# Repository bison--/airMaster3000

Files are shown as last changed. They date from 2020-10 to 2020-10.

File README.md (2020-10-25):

# airMaster3000
a ready to use CO2 sensor I build for [JujiBla](https://twitter.com/JujiBla) to use in classrooms

final build sensor assembled

This is my first ever finished and end-user ready microcontroller project ever, so bear with me about the actual build quality ^^  
To not spam the repo I might write a blogpost about the build process with more pictures (link will be HERE then).  
Short tweet about the process: https://twitter.com/bison_42/status/1317786502701645824

# Software

I used the arduino IDE and these libraries (read more about that here: https://www.arduino.cc/en/Guide/Libraries)

* LiquidCrystal 1.0.7 (build in) https://www.arduino.cc/en/Reference/LiquidCrystal
* Adafruit_CCS811 1.0.3 https://github.com/adafruit/Adafruit_CCS811

## Parts

I used (not exactly all those parts but equal): 

Name | link
---- | ----
Joy-IT CCS811 SENSOR (Luftqualitätsmesser mit I2C) | https://joy-it.net/de/products/SEN-CCS811V1 <br> https://www.conrad.de/de/p/joy-it-sen-ccs811v1-sensor-modul-1884871.html
Joy-IT 2,6" LCD Display, 16x2 (with I2C) | https://joy-it.net/de/products/SBC-LCD16x2 <br> https://www.conrad.de/de/p/joy-it-sbc-lcd16x2-display-modul-6-6-cm-2-6-zoll-16-x-2-pixel-passend-fuer-raspberry-pi-arduino-banana-pi-cubieboar-1503825.html
AZDelivery Nano V3.0 CH340 Chip, Ready Soldered Parent | https://www.amazon.de/AZDelivery-Nano-CH340-Soldered-Parent/dp/B0755S95F3/
diymore Nano I/O Extension Sensor Shield Module for Arduino UNO R3 Nano V3.0 | https://www.amazon.de/gp/product/B07D5522B6
Donau Elektronik KGB15 Euro Box Small, Black, 95 x 135 x 45 cm | https://www.amazon.de/gp/product/B005DRPCBW
TRU COMPONENTS 1PU Toggle switch (Kippschalter) 250 V/AC 1.5 A 1 x Ein/Ein rastend 1 St. | https://www.conrad.de/de/p/tru-components-1pu-kippschalter-250-v-ac-1-5-a-1-x-ein-ein-rastend-1-st-1564808.html
UNITEC 40621 Lustre Terminal 12 x 1.5-2.5 mm Pack of 10 | https://www.amazon.de/-/en/UNITEC-40621-Lustre-Terminal-1-5-2-5/dp/B007CWCQ74/
AVERY Zweckform L6009-20 Nameplate Foil Labels (45.7 x 21.2 mm on DIN A4 | https://www.amazon.de/gp/product/B0002S4DIU
random RGB-Led | ...
USB 2.0 CON.CABLE.TYPEA-MINI B (5PIN)1M | ...
Div. Jumperwire | ...
Div Wires | ...
solder | ...
hot glue | ...

## IMPROVEMENTS / PROBLEMS

While building this I discovered the library has special functions to set temperature, humidity and air preasue.  
To increase accuracy you really should add those 3 external sensors too. The integrated temperature sensor is not really useable for calibration, since it seems to use ITS temperature and not the surrounding air temperature (what's kinda obvious, because it has to warm up). Those sensors are available with an I2C interface, so you can add them directly to the existing bus.  
I tested it against my bought CO2 sensor and for environments like Cafés you really need a CO2 ONLY sensor. In fact the CCS811 goes "haywire" when more is in the air than CO2, like making a coffee or it gets close to a source like a surface desinfect. But it seems fine for environments like classrooms.

**IMPORTANT**: You REALLY should read the CCS811 datasheet! The sensor has to run for a few days to get readings that are not all over the place (they call it: burn-in).

## QA

* Q: Why Joy-IT?
* A: Because CO2 sensors are a Corona product and I wanted a REAL sensor and not a fake one. It is a trustworthy supplier and their manuals and datasheets are awesome.

## Schematics & Pictures

Thanks to [PlantProgrammer](https://plantprogrammer.com) for making the schematics 💖 .
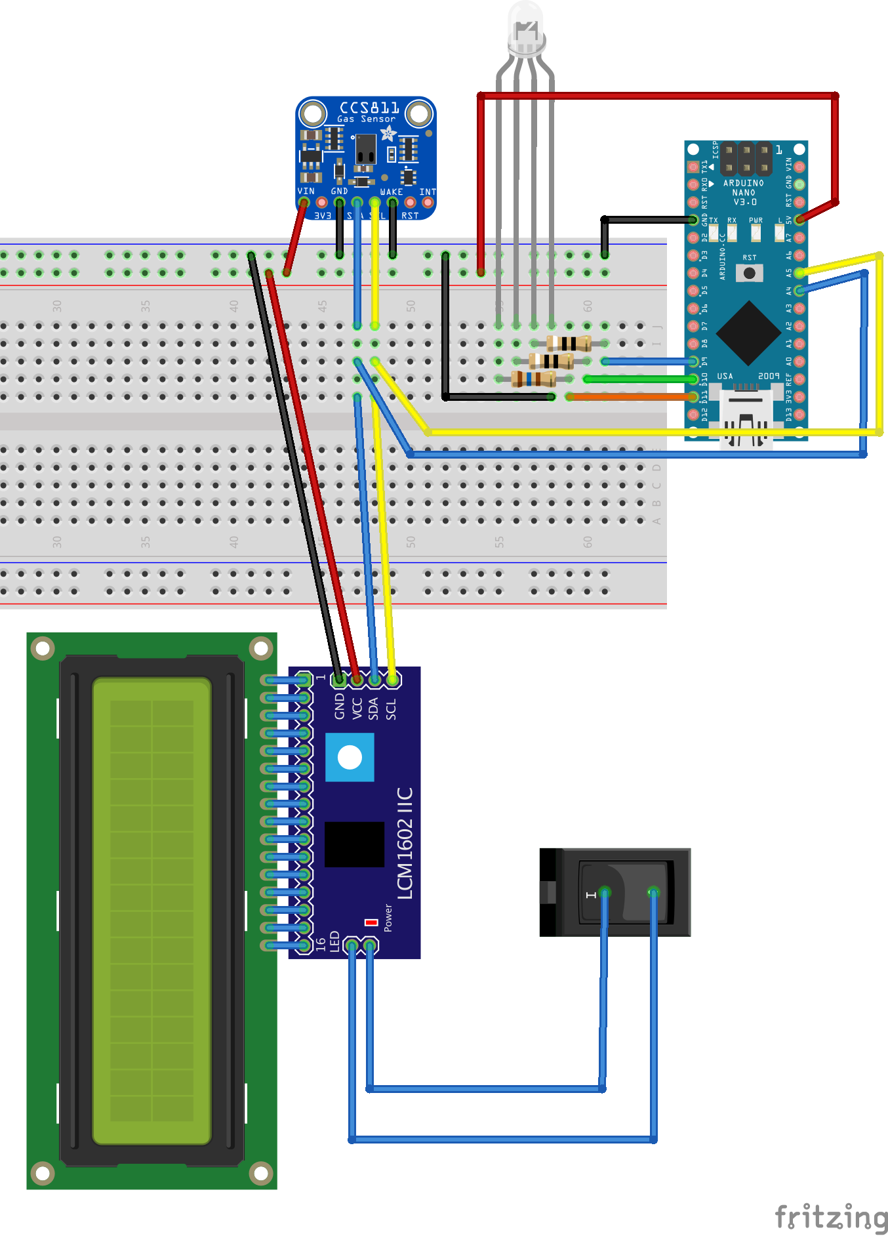
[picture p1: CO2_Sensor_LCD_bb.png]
schematics

final build sensor inner parts

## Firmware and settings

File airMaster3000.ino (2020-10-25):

#include <Wire.h>
#include <LiquidCrystal_I2C.h>
//-----Hardware Adressing-----
//in case of an not-working LCD switch commenting those 2 lines
//for a different default I2C address
LiquidCrystal_I2C lcd(0x27, 16, 2);  // default I2C address of an LCD
//LiquidCrystal_I2C lcd(0x3F,16,2);  // the other default I2C address of an LCD

#include "Adafruit_CCS811.h"
Adafruit_CCS811 ccs;

bool statusLed = false;

// the backslash character is not in the standard char set
// of the LCD so let's redefine it
uint8_t char_backslash_bytes[8] = {
    0b00000,
    0b10000,
    0b01000,
    0b00100,
    0b00010,
    0b00001,
    0b00000,
    0b00000
};

// fire animation frame 1
uint8_t char_fire1_bytes[8] = {
    0b10101,
    0b00100,
    0b01111,
    0b01111,
    0b11010,
    0b10010,
    0b11010,
    0b11010
};

// fire animation frame 2
uint8_t char_fire2_bytes[8] = {
    0b10100,
    0b00100,
    0b11110,
    0b11110,
    0b01011,
    0b01001,
    0b01011,
    0b01011
};

char fireAnimation[] = {1, 2};
int fireAnimationIndex = 0;

char activityAnimation[] = {'/', '-', 0, '|'};
int activityAnimationIndex = 0;

int led_pin_r = 11;
int led_pin_g = 10;
int led_pin_b = 9;

int backlightButton = 12;
bool backlightOn = true;  // not needed, in hardware!

bool warmUpComplete = false;
bool hasShownWelcomeMessage = false;

int line2ValueSwitch = 0;

int temperatureOffset = -20; // default: -25.0

void setup()
{
  // initialize digital pin 13/LED_BUILTIN as an output.
  // the build-in LED will be used to blink and indicate that the sensor is active
  pinMode(LED_BUILTIN, OUTPUT);
  digitalWrite(LED_BUILTIN, LOW);

  pinMode(led_pin_r, OUTPUT);
  pinMode(led_pin_g, OUTPUT);
  pinMode(led_pin_b, OUTPUT);

  //pinMode(backlightButton, INPUT);
  
  Serial.begin(9600);
  Serial.println("starting airMaster 3000");

  // upload the self-defined chars to the LCD
  lcd.init();
  lcd.createChar(0, char_backslash_bytes);
  lcd.createChar(1, char_fire1_bytes);
  lcd.createChar(2, char_fire2_bytes);
  lcd.clear();
  
  if(!ccs.begin())
  {
    digitalWrite(LED_BUILTIN, HIGH);
    Serial.println("Failed to start sensor! Please check your wiring.");

    doBacklight();
    lcd.setCursor(0, 0);
    lcd.print("sensor failed!");
    lcd.setCursor(0, 1);
    lcd.print("check wiring");
    
    while(1){delay(100);};
  }
  
  //calibrate temperature sensor
  Serial.println("calibrate temperature sensor");
  
  doBacklight();
  
  lcd.setCursor(0, 0);
  lcd.print("calibrate temp.");
  lcd.setCursor(0, 1);
  lcd.print("sensor");
  
  while(!ccs.available()) {
    blinkStatus();
  }
  float temp = ccs.calculateTemperature();
  ccs.setTempOffset(temp + temperatureOffset);
  ccs.setDriveMode(CCS811_DRIVE_MODE_1SEC);
}

void blinkStatus() {
  // 1. blink the build-in LED to indicate it's still alive
  // 2. animate a spinning thingi to indicate to the end user it's still alive
  // 3. animate a fire to indicate to the end user that the sensor is still warming up
  
  if (statusLed) {
    statusLed = false;
  } else {
    statusLed = true;
  }
  digitalWrite(LED_BUILTIN, statusLed);
  lcd.setCursor(15, 1);

  activityAnimationIndex++;
  if (activityAnimationIndex > 3) {
    activityAnimationIndex = 0;
  }
  
  lcd.print(activityAnimation[activityAnimationIndex]);
  
  // set a bool that the warmup was completed since micros will overflow in 72 hours
  if (!warmUpComplete) {
    // 20 min warmup time
    if (micros() < 1200000000) {
      lcd.setCursor(15, 0);

      fireAnimationIndex++;
      if (fireAnimationIndex > 1) {
        fireAnimationIndex = 0;
      }
      
      lcd.print(fireAnimation[fireAnimationIndex]);
    } else {
      warmUpComplete = true;
    }
  }
}

void clearLine(int rowIndex) {
  lcd.setCursor(0, rowIndex);
  lcd.print("                ");
}

void printLcdLine(String msg, int rowIndex) {
  lcd.setCursor(0, rowIndex);
  lcd.print(msg);
}

/*
 * the scrollDisplay does NOT work as I thought it would
void writeSentenceDelayed(String text, int rowIndex, int delayTime) {
  clearLine(rowIndex);
  lcd.setCursor(0, rowIndex);
  //lcd.autoscroll();
  for (int i = 0; i < text.length(); i++) {
    lcd.print(text[i]);
    lcd.scrollDisplayLeft();
    if (isSpace(text[i])) {
      delay(delayTime);
    }
  }
  //lcd.noAutoscroll();
}
*/

void welcomeMessage() {
  //String msg0 = "                "; // display length sample
    String msg1 = "Hello User      "; // future me: don't forget to change to JujiBla when updating
    String msg2 = "the sensor needs";
    String msg3 = "20m to warm up  ";
    String msg4 = "indicated by:   ";
    String msg5 = "enjoy the       ";
    String msg6 = "airMaster 3000  ";
    String msg7 = "v1.1.1          "; // software version, increment if changed
    
    printLcdLine(msg1, 0);
    delay(3000);
    
    printLcdLine(msg2, 0);
    printLcdLine(msg3, 1);
    delay(6000);
    
    printLcdLine(msg3, 0);
    printLcdLine(msg4, 1);

    lcd.setCursor(14, 1);
    lcd.print(fireAnimation[0]);
    delay(6000);

    printLcdLine(msg5, 0);
    printLcdLine(msg6, 1);
    delay(6000);

    printLcdLine(msg6, 0);
    printLcdLine(msg7, 1);
    delay(6000);
}

void setStatusLedCo2(int co2ppm)
{
  /*
   * the CO2 LED indicators from my bought CO2 sensor
   CO2
      : green
   800: yellow/orange
  1200: red
  */
  
  analogWrite(led_pin_r, 0);
  analogWrite(led_pin_g, 0);
  analogWrite(led_pin_b, 0);
  
  if (co2ppm <= 800) {
    analogWrite(led_pin_g, 10);
  } else if (co2ppm <= 1800) {
    // set to 1800 because my sensor is often a bit higher than the bought one
    // since the LED I used is... not that good I can't mix colors very well, so I use blue instead of yellow/orange
    analogWrite(led_pin_b, 20);
  } else {
    analogWrite(led_pin_r, 20);
  }
}

void setStatusLedTvoc(float tvocppb)
{
  analogWrite(led_pin_r, 0);
  analogWrite(led_pin_g, 0);
  analogWrite(led_pin_b, 0);
  
  if (tvocppb <= 25) {
    analogWrite(led_pin_g, 10);
  } else if (tvocppb <= 50) {
    analogWrite(led_pin_g, 20);
    analogWrite(led_pin_b, 20);
  } else if (tvocppb <= 100) {
    analogWrite(led_pin_b, 20);
  } else if (tvocppb <= 200) {
    analogWrite(led_pin_r, 20);
  } else {
    analogWrite(led_pin_r, 50);
  }
}

void doBacklight() {
  // i trigger the backlight always when writing to the display, otherwise it sometimes went off
  if (backlightOn) {
    lcd.backlight();
  } else {
    lcd.noBacklight();
  }
}

void loop()
{
  // read up: https://learn.sparkfun.com/tutorials/ccs811-air-quality-breakout-hookup-guide/all
  //backlightOn = digitalRead(backlightButton);
  if (ccs.available())
  {
    if (!hasShownWelcomeMessage) {
      hasShownWelcomeMessage = true;
      
      doBacklight();
      lcd.clear();

      welcomeMessage();
    }
    
    float temp = ccs.calculateTemperature();
    if(!ccs.readData())
    {
      line2ValueSwitch++;

      if (line2ValueSwitch >= 9) {
        line2ValueSwitch = 0;
      }
      
      int co2 = ccs.geteCO2();
      float tvoc = ccs.getTVOC();
      Serial.print("CO2: ");
      Serial.print(co2);
      Serial.print("ppm, TVOC: ");
      Serial.print(tvoc);
      Serial.print("ppb   Temp:");
      Serial.println(temp);

      doBacklight();
      lcd.clear();
      
      lcd.setCursor(0, 0);
      lcd.print("CO2: " + String(co2) + " ppm");

      
      // permanent TVOC display
      lcd.setCursor(0, 1);
      lcd.print("TVOC:" + String(int(tvoc)) + " ppb");
      setStatusLedCo2(co2);
      
      /*
      // debug & calibrating with temp
      if (line2ValueSwitch <= 4) {
        lcd.setCursor(0, 1);
        lcd.print("Temp: " + String(temp));
        setStatusLedCo2(co2);       
      } else if (line2ValueSwitch <= 8) {
        lcd.setCursor(0, 1);
        lcd.print("TVOC:" + String(tvoc) + " ppb");
        setStatusLedTvoc(tvoc);
      }
      */
      
      blinkStatus();
    }
    else
    {
      digitalWrite(LED_BUILTIN, HIGH);
      Serial.println("ERROR!");
      doBacklight();
      lcd.clear();
      lcd.setCursor(0, 0);
      lcd.print("ERROR! RESTART! ");
      lcd.setCursor(0, 1);
      lcd.print("HALP ME HUMAN!  ");
      while(1){delay(100);};
    }
  }
  delay(1000);
}
